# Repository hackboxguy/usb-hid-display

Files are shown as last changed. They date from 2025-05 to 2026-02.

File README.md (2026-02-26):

# usb-hid-display

A firmware for Raspberry Pi Pico (RP2040) that turns cheap off-the-shelf components (rotary encoder, push buttons, SSD1306 OLED) into a standalone USB micro-panel for embedded Linux devices.

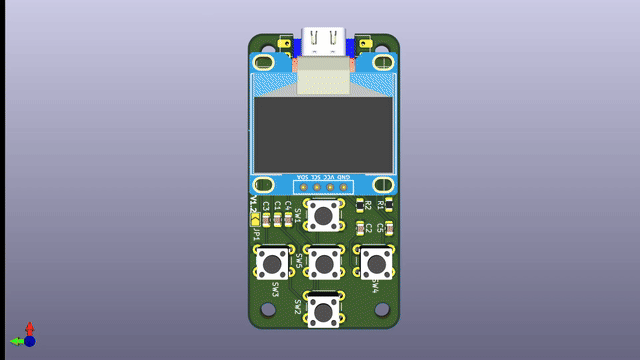
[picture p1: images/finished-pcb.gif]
RP2040-Micropanel RP2040-Micropanel 3D View


## What is this?

This firmware creates a USB composite device with two interfaces:

- **HID Mouse** — The rotary encoder and directional buttons appear as a standard USB mouse to the host. A host-side daemon (such as [micropanel](https://github.com/hackboxguy/micropanel/tree/opus_4_6_improvements)) interprets the relative mouse movements as menu navigation: up, down, left, right, and select.
- **CDC Serial** (`/dev/ttyACMx`) — The host writes binary commands over this serial port to control the SSD1306 OLED display: draw text, progress bars, set brightness, etc.

Together, these two interfaces form a self-contained hardware menu system — physical buttons for input, OLED for output — driven entirely from the host over a single USB cable. No drivers required; the device uses standard USB HID and CDC ACM classes supported by all major operating systems.

## Features

- USB HID Mouse: rotary encoder for horizontal movement, directional buttons for X/Y navigation, push button for left-click/select
- USB CDC Serial: binary command protocol to draw text, progress bars, control brightness/power/inversion on the SSD1306
- Single USB connection: both HID and CDC interfaces available simultaneously
- Robust I2C communication with timeouts (no hangs if display disconnects)
- Proper quadrature decoding with Gray code for reliable rotary input
- Per-button debouncing for all inputs
- Unique USB serial number derived from RP2040 chip ID
- Runtime landscape/portrait orientation via GPIO jumper (single firmware binary)

## Hardware Variants

### Custom PCB — RP2040-Micropanel

A purpose-built PCB designed in KiCad with a Waveshare RP2040-Zero module, SSD1306 OLED, and 5 tactile buttons on a compact board. KiCad project files are available in the [`hardware/`](hardware/) directory.

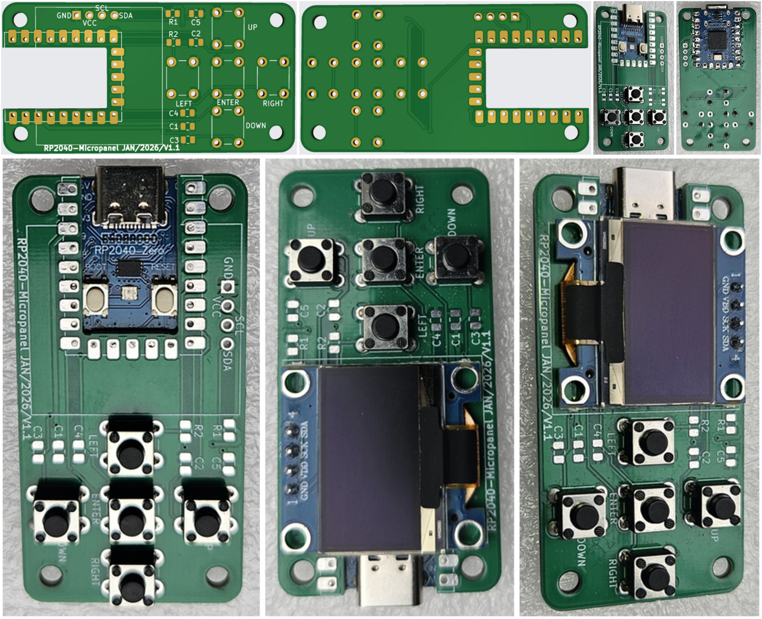
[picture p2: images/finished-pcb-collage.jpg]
RP2040-Micropanel PCB RP2040-Micropanel: KiCad renders and assembled board


### Prototype — Hand-Soldered

The same firmware runs on any RP2040 board with hand-wired connections on a general-purpose PCB. No custom PCB required — see the wiring diagram in the [Directional Push Buttons](#directional-push-buttons-active-low-directly-connected-to-gnd) section below.

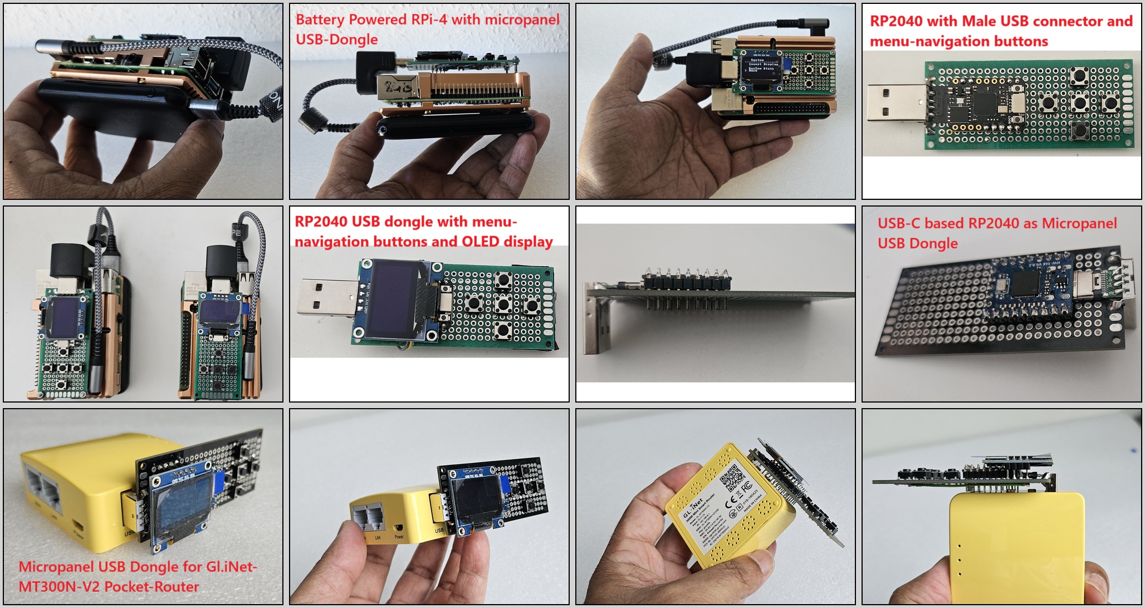
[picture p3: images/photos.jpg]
Prototype builds Various prototype builds with hand-soldered connections


## Hardware Requirements

- Raspberry Pi Pico (RP2040)
- SSD1306 OLED display (128x64, I2C version)
- Rotary encoder with push button
- 4x directional push buttons (active-low, directly connected to GPIO with internal pull-ups)
- Micro USB cable
- Optional: jumper wire for portrait mode (GPIO 27 to GND)

## Hardware Connections

### SSD1306 OLED Display (I2C)

| Signal | GPIO | Pico Pin |
|---|---|---|
| SDA | GPIO 4 | Pin 6 |
| SCL | GPIO 5 | Pin 7 |
| VCC | 3.3V | Pin 36 |
| GND | GND  | Pin 38 |

### Rotary Encoder

| Signal | GPIO | Pico Pin |
|---|---|---|
| CLK (A) | GPIO 10 | Pin 14 |
| DT (B) | GPIO 11 | Pin 15 |
| SW (Button)| GPIO 12 | Pin 16 |
| VCC | 3.3V | Pin 36 |
| GND | GND | Pin 38 |

### Orientation Jumper

The firmware detects landscape or portrait mode at boot from GPIO 27:

| GPIO 27 State | Orientation |
|---|---|
| Floating (internal pull-up → HIGH) | **Landscape** (default) |
| Connected to GND (LOW) | **Portrait** |

No separate firmware builds needed — a single `.uf2` handles both orientations. The detected orientation is reflected in the USB product string (`"USB HID Display (landscape)"` or `"USB HID Display (portrait)"`).

### Directional Push Buttons (active-low, directly connected to GND)

Pre-compiled `.uf2` binary with this GPIO config can be downloaded from [here](https://github.com/hackboxguy/usb-hid-display/blob/main/rp2040/bin/usb_hid_display.uf2?raw=true).

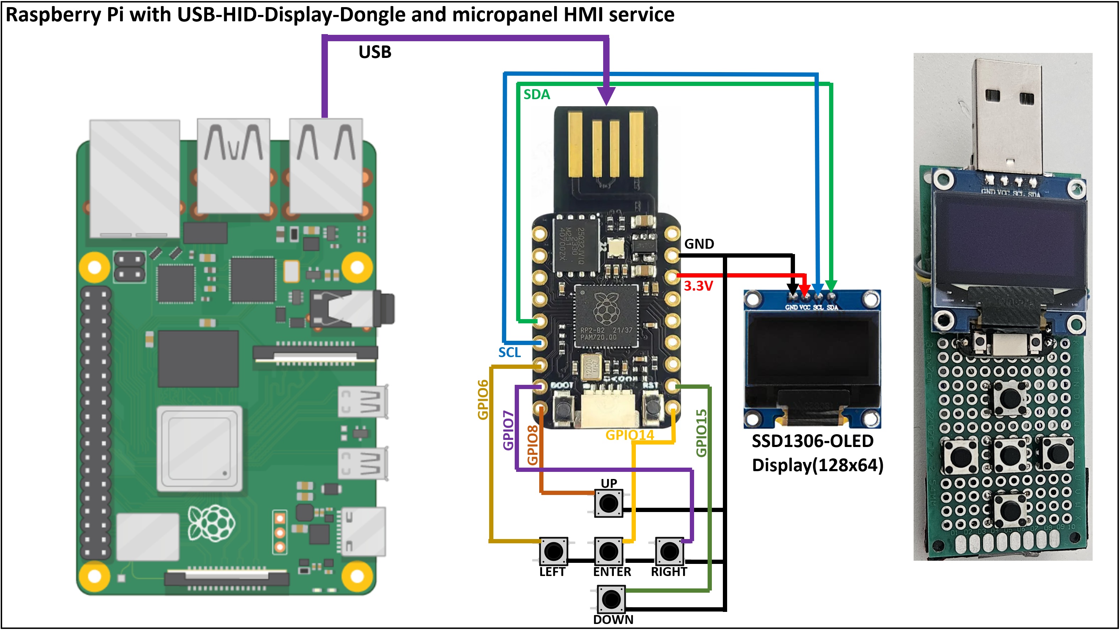
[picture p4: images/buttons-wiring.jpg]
Buttons-Wiring.


The table below shows the **landscape orientation** (default) mapping. In portrait mode, the physical button roles rotate: LEFT becomes UP, RIGHT becomes DOWN, DOWN becomes LEFT, UP becomes RIGHT.

| Button (Landscape) | GPIO | HID Action |
|---|---|---|
| LEFT | GPIO 7  | Mouse X = -5 |
| RIGHT  | GPIO 6  | Mouse X = +5 |
| UP | GPIO 8  | Mouse Y = -5 |
| DOWN | GPIO 15 | Mouse Y = +5 |
| ENTER  | GPIO 14 | Mouse Left Click (shared with rotary SW) |

Portrait/landscape mapping summary:

| Physical Button | Landscape Action | Portrait Action |
|---|---|---|
| LEFT (GPIO 7) | Left | Up |
| RIGHT (GPIO 6)  | Right | Down |
| UP (GPIO 8) | Up | Right |
| DOWN (GPIO 15)  | Down | Left |
| ENTER (GPIO 14) | Select (BTN_LEFT)| Select (BTN_LEFT) |

**Note:** Each directional button press generates two HID movement events (one immediate, one after ~16ms) to match rotary encoder step responsiveness. Host-side daemons should account for this when interpreting navigation input.

## Serial Command Protocol

The device exposes a CDC serial port (`/dev/ttyACMx`) that accepts binary commands to control the display:

| Command | Code | Format | Description |
|---|---|---|---|
| Clear | `0x01` | `[0x01]` | Clear entire display |
| Draw Text | `0x02` | `[0x02][x][y][len][text...]` | Draw `len` bytes of text at pixel position (x, y). Max len=124. Text Y is 8-pixel aligned (page-based): use multiples of 8 (0, 8, 16, 24, 32, 40, 48, 56) |
| Set Cursor | `0x03` | `[0x03][x][y]` | Set cursor to pixel position (x, y) |
| Invert  | `0x04` | `[0x04][0/1]` | Normal or inverted display mode |
| Brightness | `0x05` | `[0x05][0-255]` | Set display contrast/brightness |
| Progress Bar | `0x06` | `[0x06][x][y][w][h][0-100]` | Draw progress bar at (x, y) with width, height, and percentage |
| Power | `0x07` | `[0x07][0/1]` | Turn display off or on |

### Protocol Limits and Caveats

- `MAX_CMD_SIZE` is 128 bytes total per command buffer.
- Commands that exceed the buffer are truncated to avoid parser desynchronization.
- `CMD_DRAW_TEXT` uses length-based framing: the `len` byte specifies exactly how many text bytes follow (max 124).
- All commands have deterministic framing — fixed-length (0x01, 0x03-0x07) or length-prefixed (0x02).
- Text Y is page-based (8-pixel rows): use `0, 8, 16, ..., 56`.

### Example (Python)

```python
import serial

ser = serial.Serial('/dev/ttyACM0', timeout=1)

# Clear display
ser.write(bytes([0x01]))

# Draw text "Hello" at position (0, 0) — len=5
ser.write(bytes([0x02, 0, 0, 5]) + b'Hello')

# Draw progress bar at (10, 30), 108px wide, 12px tall, 75%
ser.write(bytes([0x06, 10, 30, 108, 12, 75]))

# Set brightness to max
ser.write(bytes([0x05, 255]))
```

## Test Commands (optional, build-time enabled)

When built with `-DENABLE_TEST_COMMANDS=ON`, the firmware accepts command `0xF0` for automated hardware testing. This allows the host test framework to inject simulated HID input events through the CDC serial port without physically pressing buttons.

Production firmware ignores `0xF0` entirely.

| Subcommand | Code | Action | HID Output |
|---|---|---|---|
| Ping | `[0xF0][0x00]` | Replies `[0xF0][0x00]` via CDC | None |
| Rotate CW | `[0xF0][0x01]` | One clockwise encoder step | REL_X = -5 |
| Rotate CCW | `[0xF0][0x02]` | One counter-clockwise step | REL_X = +5 |
| Button press | `[0xF0][0x03]` | Encoder push (press + release) | BTN_LEFT down, then up after ~50ms |
| Navigate up | `[0xF0][0x04]` | Simulated UP button | 2x REL_Y = -5 (~16ms apart) |
| Navigate down | `[0xF0][0x05]` | Simulated DOWN button | 2x REL_Y = +5 (~16ms apart) |
| Navigate left | `[0xF0][0x06]` | Simulated LEFT button | 2x REL_X = -5 (~16ms apart) |
| Navigate right | `[0xF0][0x07]` | Simulated RIGHT button | 2x REL_X = +5 (~16ms apart) |

Navigation test commands produce orientation-independent logical directions — the same HID output regardless of landscape/portrait build.

**Timing:** Allow at least 60ms between nav commands and 80ms after button press before sending the next test command. The host test framework can detect test firmware by sending ping and waiting 500ms for a reply.

## Building the Firmware

### Prerequisites

```bash
sudo apt update
sudo apt install git cmake gcc-arm-none-eabi libnewlib-arm-none-eabi build-essential libstdc++-arm-none-eabi-newlib
```

### Clone and build

```bash
git clone --recursive https://github.com/raspberrypi/pico-sdk.git ~/pico-sdk
export PICO_SDK_PATH=~/pico-sdk

git clone https://github.com/hackboxguy/usb-hid-display.git
cd usb-hid-display/rp2040/
mkdir build && cd build
cmake .. -DFIRMWARE_VERSION=1.0.0
make -j$(nproc)
```

#### Build options

| Option | Default | Description |
|---|---|---|
| `FIRMWARE_VERSION` | `0.0.0` | Firmware version in `X.Y.Z` format (each digit 0-9) |
| `ENABLE_TEST_COMMANDS` | `OFF` | Enable test/debug commands (`0xF0`) for automated testing |

`FIRMWARE_VERSION` is embedded in USB descriptors and exposed to the host via sysfs during USB enumeration. Orientation is detected at runtime from the GPIO 27 jumper (no build flag needed).

#### Test command build

To build firmware with test commands enabled (for automated hardware testing):

```bash
cmake .. -DENABLE_TEST_COMMANDS=ON -DFIRMWARE_VERSION=1.0.1
make -j$(nproc)
```

Production builds (without `-DENABLE_TEST_COMMANDS=ON`) ignore the test command byte entirely.

### Flashing

1. Hold the **BOOTSEL** button on the Pico and connect it via USB
2. The Pico mounts as a USB mass storage device
3. Copy the firmware:

```bash
# Check dmesg for the device node (e.g. /dev/sda1)
sudo mount /dev/sdXN /mnt
sudo cp usb_hid_display.uf2 /mnt/
sudo umount /mnt
```

After flashing, the device enumerates as:
- `/dev/input/eventX` -- HID mouse (rotary encoder + buttons)
- `/dev/ttyACMX` -- CDC serial port (display commands)

### Verify

```bash
# Test HID input events
sudo evtest /dev/input/eventX

# Test display commands
echo -ne '\x01' > /dev/ttyACM0          # clear display
echo -ne '\x02\x00\x00\x05Hello' > /dev/ttyACM0  # draw "Hello" at (0,0), len=5
```

## USB Device Info

| Field | Value |
|---|---|
| Vendor ID  | `0x1209` (pid.codes) |
| Product ID | `0x0001` |
| Manufacturer | hackboxguy |
| Product | `USB HID Display (<orientation>)` — reflects runtime GPIO jumper state |
| Serial | Unique per chip (from RP2040 flash ID) |
| bcdDevice | Firmware version as BCD (e.g. `0x1010` for v1.0.1) |

### Version Encoding

`FIRMWARE_VERSION=X.Y.Z` is encoded as USB `bcdDevice = 0xXYZ0`:

| Version | bcdDevice |
|---|---|
| `1.0.0` | `1000` |
| `1.0.1` | `1010` |
| `1.1.0` | `1100` |

### Reading firmware info from host

The daemon (or any tool) can read firmware version and orientation from sysfs without opening the serial port:

```bash
# Find the device (filter by VID:PID)
DEVPATH=$(grep -rl "1209" /sys/bus/usb/devices/*/idVendor 2>/dev/null | head -1 | xargs dirname)

# Read product string (includes orientation)
cat "$DEVPATH/product"    # e.g. "USB HID Display (portrait)"

# Read firmware version (BCD format)
cat "$DEVPATH/bcdDevice"  # e.g. "1100" for v1.1.0
```

## Host Integration

Use stable paths instead of raw `eventX` / `ttyACM0` indices:

```bash
# serial path
ls -l /dev/serial/by-id/

# input path
ls -l /dev/input/by-id/
```

Optional udev rule for a stable symlink:

```bash
# /etc/udev/rules.d/99-usb-hid-display.rules
SUBSYSTEM=="tty", ATTRS{idVendor}=="1209", ATTRS{idProduct}=="0001", SYMLINK+="usb-hid-display-%s{serial}"
```

```bash
sudo udevadm control --reload-rules
sudo udevadm trigger
```

## Troubleshooting

| Symptom | Likely Cause | Check / Fix |
|---|---|---|
| No `/dev/ttyACM*` | USB cable or enumeration issue | Try a data-capable cable, check `dmesg -w` |
| No HID events | Wrong `eventX` selected | Use `evtest` and pick matching device from `/dev/input/by-id` |
| Display stays blank | I2C wiring/power/address issue | Verify SDA/SCL pins, 3.3V power, GND, SSD1306 address `0x3C` |
| Buttons feel double-step | Intended dual-event behavior | Account for two events per press in daemon logic |
| Wrong navigation direction | Orientation mismatch | Check GPIO 27 jumper: GND = portrait, floating = landscape |
| Permission denied on device files | User/group access | Add user to `dialout` and `input` groups or use udev permissions |

## License

See [LICENSE](LICENSE) for details.

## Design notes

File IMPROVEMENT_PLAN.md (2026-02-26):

# USB HID Display Firmware - Improvement Plan

## Overview
Iterative improvement plan for the RP2040 USB HID Display firmware.
Each item will be implemented, tested, and verified before moving to the next.

---

## Phase 1: Critical Bug Fixes

### 1.1 Buffer overflow on CMD_DRAW_TEXT null-termination
- **File:** `rp2040/src/main.cpp:42`
- **Problem:** `serial_buf[serial_buf_pos] = 0` writes past end of `serial_buf[128]` when `serial_buf_pos == MAX_CMD_SIZE`
- **Fix:** Clamp index to `MAX_CMD_SIZE - 1` before null-terminating
- **Status:** [x] Done

### 1.2 malloc without NULL check in ssd1306_data()
- **File:** `rp2040/src/ssd1306.cpp:50-60`
- **Problem:** `malloc(len + 1)` result is dereferenced without NULL check; causes hard-fault on allocation failure
- **Fix:** Replaced with static buffer `i2c_data_buf[1025]`; removed malloc/free and `<cstdlib>` dependency entirely
- **Status:** [x] Done

### 1.3 CR/LF handler underflow on serial_buf_pos
- **File:** `rp2040/src/main.cpp:243-250`
- **Problem:** After `handle_command()` resets `serial_buf_pos` to 0, CR/LF check could process incomplete commands
- **Fix:** Strip CR/LF before processing; only call `handle_command()` if buffer still has data after strip
- **Status:** [x] Done

### 1.4 Progress bar out-of-bounds writes
- **File:** `rp2040/src/ssd1306.cpp:235-239`
- **Problem:** No validation that `x + width <= 128` or `y + height <= 64`; host-supplied values can cause `display_buffer` overflow
- **Fix:** Clamp width/height to display bounds; early return for out-of-range or degenerate dimensions
- **Status:** [x] Done

---

## Phase 2: Robustness Improvements

### 2.1 I2C calls hang forever on bus errors
- **Files:** `rp2040/src/ssd1306.cpp:47,59`
- **Problem:** `i2c_write_blocking()` will block forever if SSD1306 is disconnected or I2C bus is stuck
- **Fix:** Replaced with `i2c_write_timeout_us()` with 10ms timeout
- **Status:** [x] Done

### 2.2 Blocking sleep inside USB CDC callback
- **File:** `rp2040/src/main.cpp:193-200,305-313`
- **Problem:** `sleep_ms(5)` inside `tud_cdc_rx_cb()` blocks USB stack processing
- **Fix:** Non-blocking accumulation window using `text_cmd_pending` flag + timestamp; flushed in main loop after 5ms
- **Status:** [x] Done

### 2.3 Shared debounce timer for all direction buttons
- **File:** `rp2040/src/rotary_encoder.cpp:25-42`
- **Problem:** All 4 direction buttons shared `last_dir_btn_time`; pressing one suppresses others
- **Fix:** Each `dir_button_t` struct has its own `last_debounce_time`
- **Status:** [x] Done

### 2.4 No tud_hid_ready() check before sending reports
- **File:** `rp2040/src/rotary_encoder.cpp:111`
- **Problem:** `tud_hid_report()` called without checking if HID interface is ready
- **Fix:** Added `if (!tud_hid_ready()) return;` guard at top of `send_mouse_report()`
- **Status:** [x] Done

---

## Phase 3: Portability & Correctness

### 3.1 Signed char comparison in ssd1306_draw_char()
- **File:** `rp2040/src/ssd1306.cpp:136`
- **Problem:** `char` is unsigned on ARM by default, so `c < 0` is always false
- **Fix:** Changed to `if ((uint8_t)c > 127) c = '?';`
- **Status:** [x] Done

### 3.2 Duplicate #define between main.h and main.cpp
- **Files:** `rp2040/src/main.h`, `rp2040/src/main.cpp`
- **Problem:** Command codes defined in both files; main.h was missing newer commands
- **Fix:** All 7 command definitions consolidated in main.h; duplicates removed from main.cpp
- **Status:** [x] Done

---

## Phase 4: Features & Enhancements

### 4.1 Hardcoded serial number - use chip unique ID
- **File:** `rp2040/src/usb_descriptors.c:97-107`
- **Problem:** Serial number was hardcoded "123456"; multiple devices conflict
- **Fix:** Added `get_usb_serial()` using `pico_get_unique_board_id_string()`; lazy-initialized on first USB descriptor request
- **Status:** [x] Done

---

## Phase 5: Code Quality & Cleanup

### 5.1 Inconsistent indentation in main.cpp
- **File:** `rp2040/src/main.cpp`
- **Problem:** CMD_BRIGHTNESS and CMD_PROGRESS_BAR cases used mixed tabs/spaces
- **Fix:** Normalized to consistent 4-space indentation throughout entire file
- **Status:** [x] Done

### 5.2 Direction button code repetition
- **File:** `rp2040/src/rotary_encoder.cpp:25-42,207-234`
- **Problem:** Same logic repeated 4 times for left/right/top/bot (~80 lines)
- **Fix:** Refactored into `dir_button_t` struct array + single loop (~25 lines)
- **Status:** [x] Done

### 5.3 Dead code: direct text mode and cdc_buffer
- **File:** `rp2040/src/main.cpp`
- **Problem:** `command_mode` always true; `toggle_command_mode()` never called; direct text mode unreachable
- **Fix:** Removed `command_mode`, `cdc_buffer`, `toggle_command_mode()`, and direct text mode branch
- **Status:** [x] Done

### 5.4 PIO-based rotary encoder (optional enhancement)
- **File:** `rp2040/src/rotary_encoder.cpp`
- **Problem:** CPU-polled quadrature decoding can miss steps under load and wastes CPU cycles
- **Fix:** Implement PIO state machine for jitter-free, zero-CPU quadrature decoding
- **Status:** [ ] Pending (optional - discuss before implementing)

---

## Phase 6: Test Commands for Automated Hardware Testing

### 6.0 Add build-time test command support (0xF0)
- **Files:** `rp2040/CMakeLists.txt`, `rp2040/src/main.h`, `rp2040/src/main.cpp`, `rp2040/src/rotary_encoder.cpp`
- **Problem:** No way to inject HID input events programmatically for automated end-to-end testing
- **Fix:** Added `CMD_TEST` (0xF0) with 8 subcommands (ping, rotate CW/CCW, button press, nav up/down/left/right) behind `-DENABLE_TEST_COMMANDS=ON` build flag. Uses existing `send_mouse_report()` for byte-identical HID output. Delayed events (button release, second nav event) processed via pending event queue in main loop.
- **Status:** [x] Done

---

## Phase 7: Coordinated Protocol Improvements (requires micropanel update)

These changes require synchronized updates to both the RP2040 firmware and the micropanel daemon.

### 7.1 Add length-based framing to CMD_DRAW_TEXT
- **Files:** `rp2040/src/main.cpp`
- **Problem:** `CMD_DRAW_TEXT` (0x02) had no explicit length or terminator. The firmware used a 5ms timeout to decide when the text payload was complete — fragile under USB packet timing variation.
- **Old format:** `[0x02][x][y][text...]`
- **New format:** `[0x02][x][y][len][text...]`
- **Fix:** CDC callback now checks `serial_buf[3]` as length byte and calls `handle_command()` when `serial_buf_pos >= 4 + len`. `handle_command()` reads text from `serial_buf[4]` onwards. Safety timeout retained as fallback for stalled transfers. Pre-flush of pending text removed (no longer needed with deterministic framing).
- **Status:** [x] Done

### 7.2 Remove CR/LF fallback from binary parser
- **Files:** `rp2040/src/main.cpp`
- **Problem:** The firmware treated `\r` (0x0D) and `\n` (0x0A) as command terminators. In a binary protocol, these byte values are legitimate parameter values (e.g., x=10 is 0x0A), causing premature command finalization.
- **Fix:** Removed the CR/LF detection block. All commands now have deterministic framing: fixed-length (0x01, 0x03-0x07) or length-prefixed (0x02).
- **Status:** [x] Done

---

## Phase 8: Runtime Orientation Detection

### 8.1 GPIO jumper for landscape/portrait selection
- **Files:** `main.h`, `main.cpp`, `ssd1306.cpp`, `rotary_encoder.cpp`, `usb_descriptors.c`, `CMakeLists.txt`
- **Problem:** Required two separate firmware builds (`-DDISPLAY_ORIENTATION=portrait` vs landscape)
- **Fix:** Added runtime orientation detection via GPIO 29 jumper (GND = portrait, floating = landscape). Replaced all 7 compile-time `#ifdef DISPLAY_PORTRAIT` blocks with runtime `if (g_portrait)` checks. Removed `DISPLAY_ORIENTATION` CMake option. USB product string now dynamically reflects detected orientation.
- **Status:** [x] Done

### 8.2 Progress bar read-modify-write for shared display pages
- **File:** `rp2040/src/ssd1306.cpp`
- **Problem:** `ssd1306_draw_progress_bar()` used destructive page writes (`display_buffer[pos] = mask`), overwriting text on shared 8-pixel pages (common in portrait mode after Y-flip)
- **Fix:** Compute `bar_mask` per page (bits belonging to bar's Y range), then read-modify-write: `(display_buffer[pos] & ~bar_mask) | (mask & bar_mask)` to preserve other content
- **Status:** [x] Done

---

## Summary

- **19 of 20 items completed** (items 1.1 through 5.3, 6.0, 7.1, 7.2, 8.1, 8.2)
- **1 item pending** (5.4 PIO encoder - optional, requires discussion)
- **Files modified:** main.h, main.cpp, ssd1306.cpp, rotary_encoder.cpp, usb_descriptors.c, CMakeLists.txt
- **Next step:** Test runtime orientation with GPIO 29 jumper on hardware

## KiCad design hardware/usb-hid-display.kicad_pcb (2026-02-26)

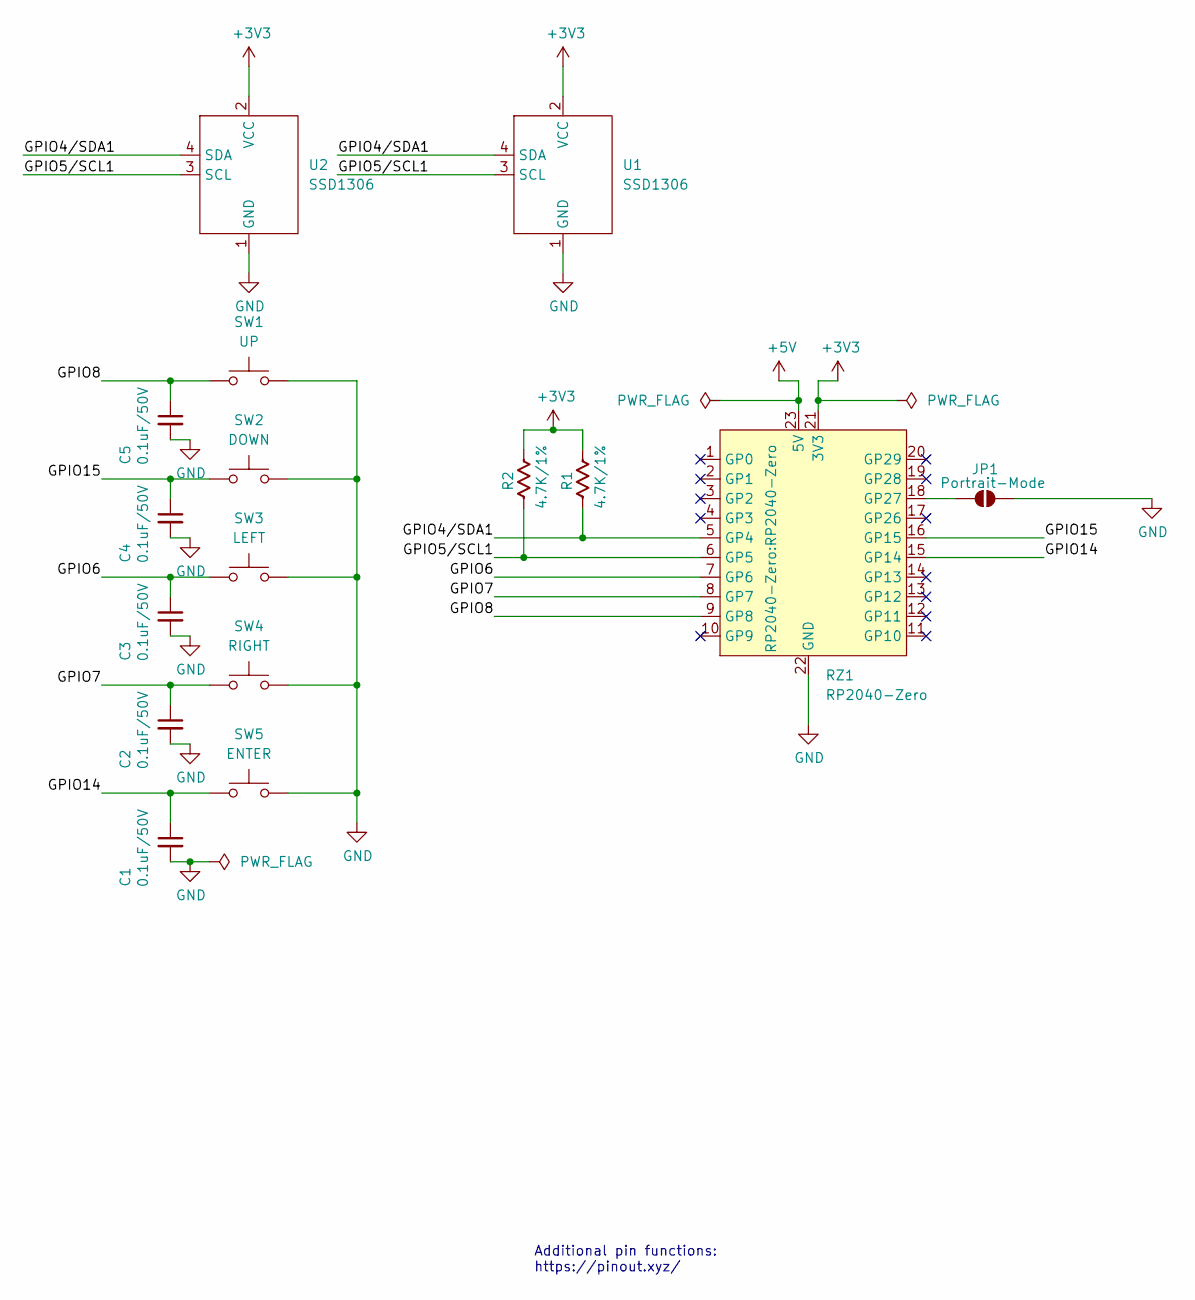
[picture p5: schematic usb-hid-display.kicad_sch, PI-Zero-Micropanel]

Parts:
C1, C2, C3, C4, C5: 0.1uF/50V; C_0805_2012Metric
JP1: Portrait-Mode; SolderJumper-2_P1.3mm_Open_TrianglePad1.0x1.5mm
R1, R2: 4.7K/1%; R_0805_2012Metric
RZ1: RP2040-Zero
SW1: UP; SW_PUSH_6mm
SW2: DOWN; SW_PUSH_6mm
SW3: LEFT; SW_PUSH_6mm
SW4: RIGHT; SW_PUSH_6mm
SW5: ENTER; SW_PUSH_6mm
U1, U2: SSD1306; ssd1306-module

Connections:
+3V3: R1.2, R2.2, RZ1.21 (3V3), U1.2 (VCC), U2.2 (VCC)
+5V: RZ1.23 (5V)
/GPIO4/SDA1: R1.1, RZ1.5 (GP4), U1.4 (SDA), U2.4 (SDA)
/GPIO5/SCL1: R2.1, RZ1.6 (GP5), U1.3 (SCL), U2.3 (SCL)
/GPIO6: C3.1, RZ1.7 (GP6), SW3.1
/GPIO7: C2.1, RZ1.8 (GP7), SW4.1
/GPIO8: C5.1, RZ1.9 (GP8), SW1.1
/GPIO14: C1.1, RZ1.15 (GP14), SW5.1
/GPIO15: C4.1, RZ1.16 (GP15), SW2.1
GND: C1.2, C2.2, C3.2, C4.2, C5.2, JP1.2 (B), RZ1.22 (GND), SW1.2, SW2.2, SW3.2, SW4.2, SW5.2, U1.1 (GND), U2.1 (GND)
unnamed: JP1.1 (A), RZ1.18 (GP27)

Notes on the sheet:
Additional pin functions: https://pinout.xyz/

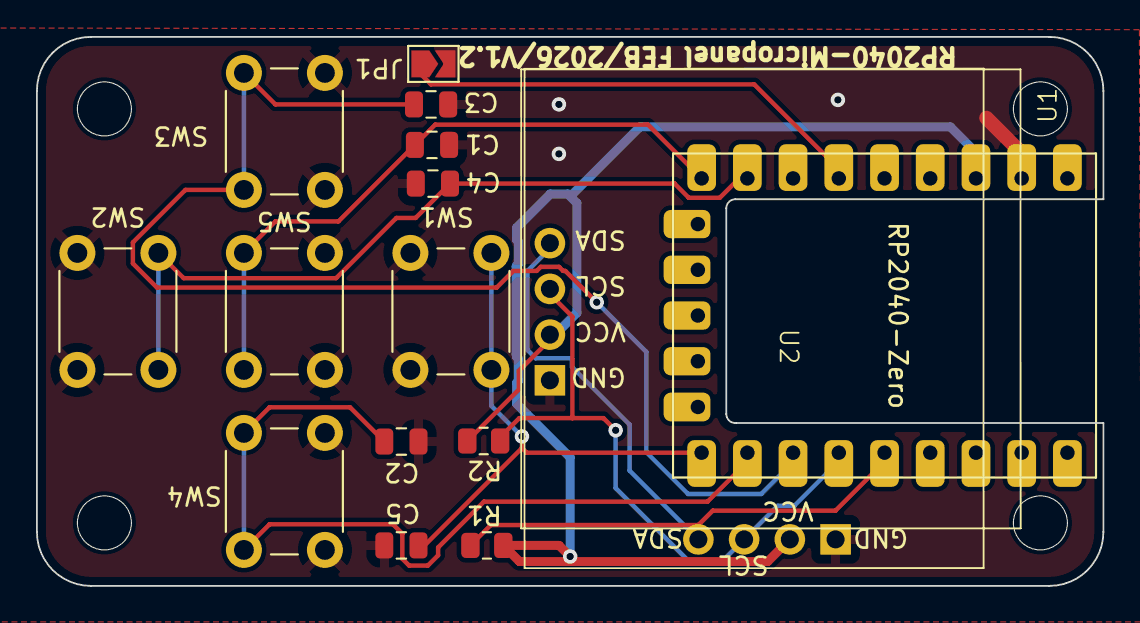
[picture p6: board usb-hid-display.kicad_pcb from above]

Board: 2 copper layers, 59.2 x 30.5 mm, 20 parts (0 on the bottom side), 10 nets.

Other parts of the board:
MH1, MH2, MH3, MH4: MountingHole_2.7mm_M2.5

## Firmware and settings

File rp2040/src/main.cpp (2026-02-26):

#include "main.h"

// Runtime orientation flag (read from GPIO jumper at boot)
bool g_portrait = false;

// Debug flag - set to false for production use
#define DEBUG_MODE      false

// Buffer for receiving commands from serial
static uint8_t serial_buf[MAX_CMD_SIZE];
static uint8_t serial_buf_pos = 0;

// Timestamp for non-blocking text accumulation (CMD_DRAW_TEXT)
static absolute_time_t text_cmd_start = {0};
static bool text_cmd_pending = false;
#define TEXT_CMD_TIMEOUT_US 5000 // 5ms accumulation window

#ifdef ENABLE_TEST_COMMANDS
// Pending test event for delayed HID reports (button release, second nav event)
static struct {
    bool pending;
    absolute_time_t fire_time;
    uint8_t buttons;
    int8_t x;
    int8_t y;
} test_pending_event = {false, {0}, 0, 0, 0};

#define TEST_BTN_RELEASE_DELAY_US 50000  // 50ms between press and release
#define TEST_NAV_SECOND_EVENT_US  16000  // 16ms between nav events (matches real buttons)

static void handle_test_command(uint8_t subcmd) {
    // Warn if a pending event will be overwritten (debug aid for test timing issues)
    if (test_pending_event.pending && DEBUG_MODE) {
        ssd1306_draw_text(0, 48, "WARN:test evt overwrite");
    }

    switch (subcmd) {
        case TEST_SUBCMD_PING:
        {
            uint8_t reply[2] = {CMD_TEST, TEST_SUBCMD_PING};
            tud_cdc_write(reply, 2);
            tud_cdc_write_flush();
            break;
        }
        case TEST_SUBCMD_ROTATE_CW:
            send_mouse_report(0, -5, 0, 0);
            break;

        case TEST_SUBCMD_ROTATE_CCW:
            send_mouse_report(0, 5, 0, 0);
            break;

        case TEST_SUBCMD_BTN_PRESS:
            // Send press immediately, queue release after 50ms
            send_mouse_report(1, 0, 0, 0);
            test_pending_event.pending = true;
            test_pending_event.fire_time = make_timeout_time_us(TEST_BTN_RELEASE_DELAY_US);
            test_pending_event.buttons = 0;
            test_pending_event.x = 0;
            test_pending_event.y = 0;
            break;

        case TEST_SUBCMD_NAV_UP:
            send_mouse_report(0, 0, -5, 0);
            test_pending_event.pending = true;
            test_pending_event.fire_time = make_timeout_time_us(TEST_NAV_SECOND_EVENT_US);
            test_pending_event.buttons = 0;
            test_pending_event.x = 0;
            test_pending_event.y = -5;
            break;

        case TEST_SUBCMD_NAV_DOWN:
            send_mouse_report(0, 0, 5, 0);
            test_pending_event.pending = true;
            test_pending_event.fire_time = make_timeout_time_us(TEST_NAV_SECOND_EVENT_US);
            test_pending_event.buttons = 0;
            test_pending_event.x = 0;
            test_pending_event.y = 5;
            break;

        case TEST_SUBCMD_NAV_LEFT:
            send_mouse_report(0, -5, 0, 0);
            test_pending_event.pending = true;
            test_pending_event.fire_time = make_timeout_time_us(TEST_NAV_SECOND_EVENT_US);
            test_pending_event.buttons = 0;
            test_pending_event.x = -5;
            test_pending_event.y = 0;
            break;

        case TEST_SUBCMD_NAV_RIGHT:
            send_mouse_report(0, 5, 0, 0);
            test_pending_event.pending = true;
            test_pending_event.fire_time = make_timeout_time_us(TEST_NAV_SECOND_EVENT_US);
            test_pending_event.buttons = 0;
            test_pending_event.x = 5;
            test_pending_event.y = 0;
            break;

        default:
            break;
    }
}
#endif // ENABLE_TEST_COMMANDS

// Handles a serial command once received
void handle_command() {
    // Check for minimum command length (1 byte for command type at least)
    if (serial_buf_pos < 1) return;

    // Debug info should only be displayed if debug mode is enabled
    if (DEBUG_MODE) {
        char debug_buf[32];
        snprintf(debug_buf, sizeof(debug_buf), "CMD: %02X LEN: %d", serial_buf[0], serial_buf_pos);
        // Save current display content to draw debug info at bottom
        ssd1306_draw_text(0, 56, debug_buf);
    }

    // Process command based on first byte
    switch (serial_buf[0]) {
        case CMD_CLEAR:
            // Simply clear the display without adding any debug text
            ssd1306_clear();
            break;

        case CMD_DRAW_TEXT:
            // Format: CMD_DRAW_TEXT, x, y, len, text...
            if (serial_buf_pos >= 5) {
                uint8_t x = serial_buf[1];
                uint8_t y = serial_buf[2];
                uint8_t text_len = serial_buf[3];

                // Clamp text length to available buffer
                if (text_len > MAX_CMD_SIZE - 4) text_len = MAX_CMD_SIZE - 4;
                if (text_len > serial_buf_pos - 4) text_len = serial_buf_pos - 4;

                // Null-terminate the text
                serial_buf[4 + text_len] = 0;

                // Draw text starting from position 4 in buffer
                ssd1306_draw_text(x, y, (char*)&serial_buf[4]);
            }
            break;

        case CMD_SET_CURSOR:
            // Format: CMD_SET_CURSOR, x, y
            if (serial_buf_pos >= 3) {
                uint8_t x = serial_buf[1];
                uint8_t y = serial_buf[2];
                ssd1306_set_cursor(x, y);
                
                if (DEBUG_MODE) {
                    char debug_buf[32];
                    snprintf(debug_buf, sizeof(debug_buf), "Cursor: %d,%d", x, y);
                    ssd1306_draw_text(0, 48, debug_buf);
                }
            }
            break;

        case CMD_INVERT:
            // Format: CMD_INVERT, value (0 or 1)
            if (serial_buf_pos >= 2) {
                bool invert = serial_buf[1] > 0;
                ssd1306_invert(invert);
                
                if (DEBUG_MODE) {
                    ssd1306_draw_text(0, 48, invert ? "Invert: ON" : "Invert: OFF");
                }
            }
            break;
        case CMD_BRIGHTNESS:
            // Format: CMD_BRIGHTNESS, brightness_level (0-255)
            if (serial_buf_pos >= 2) {
                uint8_t brightness = serial_buf[1];
                ssd1306_set_brightness(brightness);

                if (DEBUG_MODE) {
                    char debug_buf[32];
                    snprintf(debug_buf, sizeof(debug_buf), "Brightness: %d", brightness);
                    ssd1306_draw_text(0, 48, debug_buf);
                }
            }
            break;

        case CMD_PROGRESS_BAR:
            // Format: CMD_PROGRESS_BAR, x, y, width, height, progress (0-100)
            if (serial_buf_pos >= 6) {
                uint8_t x = serial_buf[1];
                uint8_t y = serial_buf[2];
                uint8_t width = serial_buf[3];
                uint8_t height = serial_buf[4];
                uint8_t progress = serial_buf[5];

                ssd1306_draw_progress_bar(x, y, width, height, progress);

                if (DEBUG_MODE) {
                    char debug_buf[32];
                    snprintf(debug_buf, sizeof(debug_buf), "Progress: %d%%", progress);
                    ssd1306_draw_text(0, 48, debug_buf);
                }
            }
            break;

        case CMD_POWER:
            // Format: CMD_POWER, value (0 or 1)
            if (serial_buf_pos >= 2) {
                bool power = serial_buf[1] > 0;
                ssd1306_power(power);

                if (DEBUG_MODE) {
                    ssd1306_draw_text(0, 48, power ? "Power: ON" : "Power: OFF");
                }
            }
            break;

        default:
            // Unknown command
            if (DEBUG_MODE) {
                char debug_buf[32];
                snprintf(debug_buf, sizeof(debug_buf), "Unknown CMD: %02X", serial_buf[0]);
                ssd1306_draw_text(0, 48, debug_buf);
            }
            break;
    }

    // Reset buffer position for next command
    serial_buf_pos = 0;
}

// CDC callback when line state changes
void tud_cdc_line_state_cb(uint8_t itf, bool dtr, bool rts) {
    (void) itf;
    (void) rts;

    // When DTR is deasserted, reset the command buffer
    if (!dtr) {
        serial_buf_pos = 0;
        text_cmd_pending = false;
    }
}

// CDC callback when data is received
void tud_cdc_rx_cb(uint8_t itf) {
    (void) itf;

    // Process structured commands
    // Read data until FIFO is empty or buffer is full
    uint8_t cmd_type = 0;
    bool has_cmd_type = false;

    // If we already have data in the buffer, get the command type
    if (serial_buf_pos > 0) {
        cmd_type = serial_buf[0];
        has_cmd_type = true;
    }

    // Read available data
    while (tud_cdc_available() && serial_buf_pos < MAX_CMD_SIZE) {
        uint8_t c;
        tud_cdc_read(&c, 1);

        // Add byte to buffer
        serial_buf[serial_buf_pos++] = c;

        // If this is the first byte, it's our command type
        if (serial_buf_pos == 1) {
            cmd_type = c;
            has_cmd_type = true;
        }
    }

    // If buffer is full but CDC still has data, drain excess to prevent
    // leftover bytes being misinterpreted as the next command header
    if (serial_buf_pos >= MAX_CMD_SIZE) {
        uint8_t discard;
        while (tud_cdc_available()) {
            tud_cdc_read(&discard, 1);
        }
    }

    // If we don't have at least a command type yet, wait for more data
    if (!has_cmd_type) return;

    // Process commands based on type
    switch (cmd_type) {
        case CMD_CLEAR:
            // Clear command only needs one byte
            if (serial_buf_pos >= 1) {
                handle_command();
            }
            break;

        case CMD_DRAW_TEXT:
            // Format: [0x02][x][y][len][text...] — length-based framing
            if (serial_buf_pos >= 4) {
                uint8_t text_len = serial_buf[3];
                if (text_len > MAX_CMD_SIZE - 4) text_len = MAX_CMD_SIZE - 4;
                if (serial_buf_pos >= (uint8_t)(4 + text_len)) {
                    // All text bytes received — process immediately
                    handle_command();
                    text_cmd_pending = false;
                } else if (!text_cmd_pending) {
                    // Still waiting for text bytes — start safety timeout
                    text_cmd_start = get_absolute_time();
                    text_cmd_pending = true;
                }
            }
            break;

        case CMD_SET_CURSOR:
            // Set cursor requires 3 bytes
            if (serial_buf_pos >= 3) {
                handle_command();
            }
            break;

        case CMD_INVERT:
            // Invert requires 2 bytes
            if (serial_buf_pos >= 2) {
                handle_command();
            }
            break;

        case CMD_BRIGHTNESS:
            // Brightness requires 2 bytes
            if (serial_buf_pos >= 2) {
                handle_command();
            }
            break;

        case CMD_PROGRESS_BAR:
            // Progress bar requires 6 bytes
            if (serial_buf_pos >= 6) {
                handle_command();
            }
            break;

        case CMD_POWER:
            // Power requires 2 bytes
            if (serial_buf_pos >= 2) {
                handle_command();
            }
            break;

#ifdef ENABLE_TEST_COMMANDS
        case CMD_TEST:
            // Test command requires 2 bytes: [0xF0][subcommand]
            if (serial_buf_pos >= 2) {
                handle_test_command(serial_buf[1]);
                serial_buf_pos = 0;
            }
            break;
#endif

        default:
            // Unknown command, just reset the buffer
            serial_buf_pos = 0;
            break;
    }

}

// HID callbacks
uint16_t tud_hid_get_report_cb(uint8_t instance, uint8_t report_id, hid_report_type_t report_type, uint8_t* buffer, uint16_t reqlen) {
    (void) instance;
    (void) report_id;
    (void) report_type;
    (void) buffer;
    (void) reqlen;

    return 0;  // Not implemented, just stub to avoid linker error
}

void tud_hid_set_report_cb(uint8_t instance, uint8_t report_id, hid_report_type_t report_type, uint8_t const* buffer, uint16_t bufsize) {
    (void) instance;
    (void) report_id;
    (void) report_type;
    (void) buffer;
    (void) bufsize;

    // Not implemented, just stub to avoid linker error
}

int main() {
    // Initialize board
    stdio_init_all();

    // Read orientation jumper before USB init (so product string is correct)
    gpio_init(ORIENTATION_PIN);
    gpio_set_dir(ORIENTATION_PIN, GPIO_IN);
    gpio_pull_up(ORIENTATION_PIN);
    sleep_us(10); // Let pull-up settle
    g_portrait = !gpio_get(ORIENTATION_PIN); // LOW = portrait, HIGH = landscape

    // Initialize TinyUSB
    tusb_init();

    // Initialize the SSD1306 OLED display
    ssd1306_init();

    // Initialize the rotary encoder
    setup_rotary_encoder();

    // Display startup message - only show briefly
    ssd1306_clear();
    //ssd1306_draw_text(0, 0, "USB HID Display");
    ssd1306_draw_text(0, 0, "Booting.......");
    //ssd1306_draw_text(0, 16, "Ready...");
    
    // Wait a moment to show startup message then clear
    sleep_ms(2000);
    //ssd1306_clear();

    // Main loop
    while (1) {
        // TinyUSB device task
        tud_task();

        // Process rotary encoder
        process_rotary_encoder();

        // Safety fallback: flush CMD_DRAW_TEXT if transfer stalls (length-based
        // framing should complete before this, but protects against incomplete sends)
        if (text_cmd_pending && absolute_time_diff_us(text_cmd_start, get_absolute_time()) >= TEXT_CMD_TIMEOUT_US) {
            // Read any last data that arrived
            while (tud_cdc_available() && serial_buf_pos < MAX_CMD_SIZE) {
                tud_cdc_read(&serial_buf[serial_buf_pos++], 1);
            }
            handle_command();
            text_cmd_pending = false;
        }

#ifdef ENABLE_TEST_COMMANDS
        // Fire pending test event (delayed button release or second nav event)
        if (test_pending_event.pending && absolute_time_diff_us(test_pending_event.fire_time, get_absolute_time()) >= 0) {
            send_mouse_report(test_pending_event.buttons, test_pending_event.x, test_pending_event.y, 0);
            test_pending_event.pending = false;
        }
#endif

        // Handle CDC data processing more aggressively
        uint32_t start = time_us_32();
        
        // Check multiple times for CDC data during each loop cycle
        for (int i = 0; i < 10 && (time_us_32() - start < 1000); i++) {
            // Process CDC data if available
            if (tud_cdc_available()) {
                // Handle incoming data with appropriate callback
                tud_cdc_rx_cb(0);
            }
            
            // Give USB stack time to process data
            tud_task();
            
            // Small yield
            sleep_us(10);
        }
        
        // Small delay to avoid hogging the CPU
        sleep_us(100);
    }

    return 0;
}

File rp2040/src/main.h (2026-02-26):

#ifndef MAIN_H
#define MAIN_H

#include <stdio.h>
#include <string.h>
#include "pico/stdlib.h"
#include "hardware/i2c.h"
#include "hardware/gpio.h"
#include "pico/unique_id.h"
#include "tusb.h"

// Orientation jumper: GPIO 27 to GND = portrait, floating (pull-up) = landscape
#define ORIENTATION_PIN 27
extern bool g_portrait;

// I2C defines
#define I2C_PORT        i2c0
#define I2C_SDA_PIN     4
#define I2C_SCL_PIN     5

// SSD1306 defines
#define SSD1306_ADDR    0x3C

// Serial protocol commands
#define CMD_CLEAR        0x01
#define CMD_DRAW_TEXT    0x02
#define CMD_SET_CURSOR   0x03
#define CMD_INVERT       0x04
#define CMD_BRIGHTNESS   0x05
#define CMD_PROGRESS_BAR 0x06
#define CMD_POWER        0x07
#define CMD_TEST         0xF0  // Test/debug command (enabled by ENABLE_TEST_COMMANDS)

// Test command subcommands
#define TEST_SUBCMD_PING       0x00
#define TEST_SUBCMD_ROTATE_CW  0x01
#define TEST_SUBCMD_ROTATE_CCW 0x02
#define TEST_SUBCMD_BTN_PRESS  0x03
#define TEST_SUBCMD_NAV_UP     0x04
#define TEST_SUBCMD_NAV_DOWN   0x05
#define TEST_SUBCMD_NAV_LEFT   0x06
#define TEST_SUBCMD_NAV_RIGHT  0x07

// Buffer sizes
#define MAX_CMD_SIZE     128

// Function declarations only (no implementations)
void ssd1306_init();
void ssd1306_clear();
void ssd1306_draw_text(uint8_t x, uint8_t y, const char* text);
void ssd1306_invert(bool invert);
void ssd1306_power(bool power);
void ssd1306_set_cursor(uint8_t x, uint8_t y);
void ssd1306_set_brightness(uint8_t brightness);
void ssd1306_draw_progress_bar(uint8_t x, uint8_t y, uint8_t width, uint8_t height, uint8_t progress);

// Rotary encoder functions
void setup_rotary_encoder();
void process_rotary_encoder();

// HID report function (used by rotary encoder and test commands)
void send_mouse_report(uint8_t buttons, int8_t x, int8_t y, int8_t wheel);

#endif // MAIN_H

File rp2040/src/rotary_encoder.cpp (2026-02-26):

#include "main.h"

// Rotary encoder GPIO pins
#define ROTARY_CLK_PIN  10
#define ROTARY_DT_PIN   11
#define ROTARY_SW_PIN   12

//gpio config for up/down/left/right directional buttons
#define LEFT_BTN_PIN    7  // REL_X value -5
#define RIGHT_BTN_PIN   6  // REL_X value 5
#define TOP_BTN_PIN     15 // REL_Y value 5(mapped to down button)
#define BOT_BTN_PIN     8  // REL_Y value -5(mapped to up button)
#define ENTER_BTN_PIN   14 // MOUSE_BTN_LEFT (active-low, directly connected)

// Global state variables
static int last_clk_state = 0;
static int last_dt_state = 0;
static volatile bool button_state = false; // Written in IRQ, read in main loop
static volatile bool button_changed = false; // Written in IRQ, read in main loop
static volatile uint32_t last_button_time_us = 0; // For debouncing (atomic 32-bit, IRQ-safe)
static absolute_time_t last_rotation_time = {0}; // For rotation debouncing
static const uint32_t DEBOUNCE_TIME_US = 5000; // 5ms debounce (increased)
static bool last_report_state = false; // Track last reported button state

// Direction button configuration and state
typedef struct {
    uint gpio_pin;
    int8_t rel_x;
    int8_t rel_y;
    bool last_state;
    absolute_time_t last_debounce_time;
    bool second_pending;
    absolute_time_t first_event_time;
} dir_button_t;

#define NUM_DIR_BUTTONS 4
// Landscape (default) — portrait mapping applied at runtime in setup_rotary_encoder()
static dir_button_t dir_buttons[NUM_DIR_BUTTONS] = {
    { LEFT_BTN_PIN,   -5,  0, false, {0}, false, {0} },  // Left
    { RIGHT_BTN_PIN,   5,  0, false, {0}, false, {0} },  // Right
    { TOP_BTN_PIN,     0, -5, false, {0}, false, {0} },  // Top
    { BOT_BTN_PIN,     0,  5, false, {0}, false, {0} },  // Bottom
};
static const uint32_t SECOND_EVENT_DELAY_US = 16000; // 16ms between events to match rotary

// Mouse report structure
typedef struct {
    uint8_t buttons;
    int8_t x;
    int8_t y;
    int8_t wheel;
} mouse_report_t;

// Read combined button state: pressed if either ROTARY_SW or ENTER is pressed
static bool read_button_pressed() {
    return !gpio_get(ROTARY_SW_PIN) || !gpio_get(ENTER_BTN_PIN);
}

// Callback for button pin interrupt (handles both ROTARY_SW and ENTER)
static void button_callback(uint gpio, uint32_t events) {
    uint32_t now_us = time_us_32();

    // Debounce protection
    if ((now_us - last_button_time_us) < DEBOUNCE_TIME_US) {
        return;
    }

    last_button_time_us = now_us;

    if (gpio == ROTARY_SW_PIN || gpio == ENTER_BTN_PIN) {
        bool new_state = read_button_pressed();

        // Only process if state actually changed
        if (new_state != button_state) {
            button_state = new_state;
            button_changed = true;
        }
    }
}

// Initialize rotary encoder and button GPIO
void setup_rotary_encoder() {
    // Initialize CLK and DT pins with pull-ups
    gpio_init(ROTARY_CLK_PIN);
    gpio_init(ROTARY_DT_PIN);
    gpio_set_dir(ROTARY_CLK_PIN, GPIO_IN);
    gpio_set_dir(ROTARY_DT_PIN, GPIO_IN);
    gpio_pull_up(ROTARY_CLK_PIN);
    gpio_pull_up(ROTARY_DT_PIN);

    // Initialize rotary encoder button pin with pull-up and interrupts
    gpio_init(ROTARY_SW_PIN);
    gpio_set_dir(ROTARY_SW_PIN, GPIO_IN);
    gpio_pull_up(ROTARY_SW_PIN);
    gpio_set_irq_enabled_with_callback(ROTARY_SW_PIN,
                                      GPIO_IRQ_EDGE_FALL | GPIO_IRQ_EDGE_RISE,
                                      true, &button_callback);

    // Initialize standalone ENTER button with pull-up and interrupts
    gpio_init(ENTER_BTN_PIN);
    gpio_set_dir(ENTER_BTN_PIN, GPIO_IN);
    gpio_pull_up(ENTER_BTN_PIN);
    gpio_set_irq_enabled(ENTER_BTN_PIN,
                         GPIO_IRQ_EDGE_FALL | GPIO_IRQ_EDGE_RISE,
                         true);

    // Apply portrait button mapping if jumper is set
    // Portrait rotates 90° CCW: LEFT→UP, RIGHT→DOWN, TOP→RIGHT, BOT→LEFT
    if (g_portrait) {
        // Portrait mapping: (rel_x, rel_y)
        // LEFT:  (-5, 0) → (0, -5)   RIGHT: (5, 0) → (0, 5)
        // TOP:   (0, -5) → (5, 0)    BOT:   (0, 5) → (-5, 0)
        static const int8_t portrait_map[NUM_DIR_BUTTONS][2] = {
            { 0, -5}, { 0,  5}, { 5,  0}, {-5,  0}
        };
        for (int i = 0; i < NUM_DIR_BUTTONS; i++) {
            dir_buttons[i].rel_x = portrait_map[i][0];
            dir_buttons[i].rel_y = portrait_map[i][1];
        }
    }

    // Initialize direction buttons with pull-up (since they're active low)
    for (int i = 0; i < NUM_DIR_BUTTONS; i++) {
        gpio_init(dir_buttons[i].gpio_pin);
        gpio_set_dir(dir_buttons[i].gpio_pin, GPIO_IN);
        gpio_pull_up(dir_buttons[i].gpio_pin);
        dir_buttons[i].last_state = !gpio_get(dir_buttons[i].gpio_pin);
    }

    // Initialize rotary encoder states
    last_clk_state = gpio_get(ROTARY_CLK_PIN);
    last_dt_state = gpio_get(ROTARY_DT_PIN);
    button_state = read_button_pressed(); // Either ROTARY_SW or ENTER
    last_report_state = button_state; // Initialize to match
}

// Send a mouse report (non-static: also called by test commands)
void send_mouse_report(uint8_t buttons, int8_t x, int8_t y, int8_t wheel) {
    if (!tud_hid_ready()) return;

    mouse_report_t report = {
        .buttons = buttons,
        .x = x,
        .y = y,
        .wheel = wheel
    };

    // Send report
    tud_hid_report(0, &report, sizeof(report));

    // Ensure the packet is sent
    tud_task();

    // Small delay to ensure report is processed
    sleep_us(500);
}
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

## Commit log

2025-04-16 added first working version of usb-composite-device fmw for rp2040
2025-04-16 reversed KEY_REL value for clock-wise and counter-clockwise direction of rotary encoder
    [rotary_encoder.cpp]
2025-04-18 added ssd1306 power on/off command
2025-04-25 updated README.md for directional push button support
2025-04-25 updated binary as per latest directional push-button support
2025-04-30 changed directional button gpio for easy soldering of io pins for rp2040 usb dongle
2025-05-30 updated readme.md with buttons-wiring.jpg picture
2025-05-30 updated readme and code and picture as per updated gpio config for directional push buttons
2026-02-07 changed the top-bottom buttons for landscape orientation
2026-02-20 firmware: fix bugs, improve robustness, refactor and update docs
    Bug fixes:
    - Fix buffer overflow on CMD_DRAW_TEXT null-termination (serial_buf)
    - Replace malloc with static buffer in ssd1306_data() to prevent hard-fault
    - Fix CR/LF command terminator underflow on serial_buf_pos
    - Fix progress bar out-of-bounds writes with display bounds clamping
    - Fix signed char comparison in ssd1306_draw_char() for ARM portability
    - Fix shared debounce timer causing dropped simultaneous button presses
    Robustness improvements:
    - Replace i2c_write_blocking() with i2c_write_timeout_us() (scaled per transfer size)
    - Replace blocking sleep_ms(5) in CDC callback with non-blocking text accumulation
    - Add tud_hi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
    [main.cpp, main.h, rotary_encoder.cpp]
2026-02-21 fix: address codex review findings F2, F3, F5, F6, F8
    - Add volatile qualifier to IRQ-shared button_state and button_changed
    variables to prevent compiler optimization issues (F2)
    - Drain excess CDC bytes when serial buffer is full to prevent protocol
    desynchronization on long text payloads (F3)
    - Document dual HID events per directional button press (F5)
    - Clarify 8-pixel Y alignment for text rendering in protocol docs (F6)
    - Add landscape/portrait orientation mapping note for buttons (F8)
    [main.cpp, rotary_encoder.cpp]
2026-02-21 fix: check I2C return values and bail on display disconnect (F7)
    ssd1306_command() and ssd1306_data() now return bool indicating I2C
    success. All callers (clear, draw_char, progress_bar) bail early on
    failure, preventing cascading timeout stalls when display is
    disconnected. Display auto-recovers on next successful I2C write.
2026-02-21 fix: make button debounce timestamp IRQ-safe with atomic 32-bit access (R1)
    Replace 64-bit absolute_time_t last_button_time with volatile uint32_t
    last_button_time_us using time_us_32(). On Cortex-M0+ (RP2040), 64-bit
    struct access can tear between IRQ and main loop. 32-bit reads/writes
    are atomic, eliminating rare debounce anomalies.
    [rotary_encoder.cpp]
2026-02-21 feat: add compile-time portrait orientation with SW 180° display rotation
    Add DISPLAY_ORIENTATION cmake option (landscape/portrait). Portrait mode
    rotates button mappings 90° CCW, flips text rendering bottom-to-top, and
    applies software 180° character rotation for upside-down display mounting.
    [rotary_encoder.cpp]
2026-02-21 docs: add protocol caveats, host integration, and troubleshooting to README
    Add portrait/landscape button mapping table, protocol limits and caveats,
    version encoding examples, host integration with udev rule, and
    troubleshooting guide.
2026-02-21 feat: add test commands (0xF0) for automated hardware testing
    Add build-time optional test command support behind -DENABLE_TEST_COMMANDS=ON.
    Enables host-side test frameworks to inject HID input events (rotary, buttons,
    navigation) through CDC serial for end-to-end automated testing.
2026-02-21 feat: length-based CMD_DRAW_TEXT framing and remove CR/LF fallback
    Change CMD_DRAW_TEXT format from [0x02][x][y][text...] to
    [0x02][x][y][len][text...] for deterministic framing. Remove CR/LF
    fallback from binary parser — all commands now have fixed-length or
    length-prefixed framing. Safety timeout retained for stalled transfers.
    [main.cpp]
2026-02-24 feat: runtime orientation via GPIO 27 jumper, remap rotary encoder to GPIO 10/11/12
    Replace compile-time landscape/portrait builds with single firmware that
    detects orientation at boot from GPIO 27 (GND=portrait, floating=landscape).
    All #ifdef DISPLAY_PORTRAIT blocks converted to runtime if(g_portrait) checks.
    USB product string reflects detected orientation dynamically.
    Remap rotary encoder from GPIO 26/27/14 to GPIO 10/11/12. Separate ENTER
    button (GPIO 14) from rotary SW (GPIO 12) — both generate left-click via
    combined read_button_pressed() helper.
    [main.cpp, main.h, rotary_encoder.cpp]
2026-02-24 docs: add custom PCB images and hardware variants section to README
    Replace hero image with animated 3D PCB GIF. Add "Hardware Variants"
    section showing both the custom KiCad-designed RP2040-Micropanel PCB
    (collage of renders and assembled photos) and the hand-soldered
    prototype builds.
2026-02-24 feat: add KiCad PCB design files for RP2040-Micropanel board
    Renamed from adav-pi-zero-hat-v1 to usb-hid-display and updated all
    internal project references. Excludes .kicad_prl (user-local) and
    .step (10MB 3D model).
    [usb-hid-display.kicad_pcb, usb-hid-display.kicad_sch]
